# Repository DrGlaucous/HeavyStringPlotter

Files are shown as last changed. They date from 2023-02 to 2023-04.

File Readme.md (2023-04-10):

  

## String Plotter

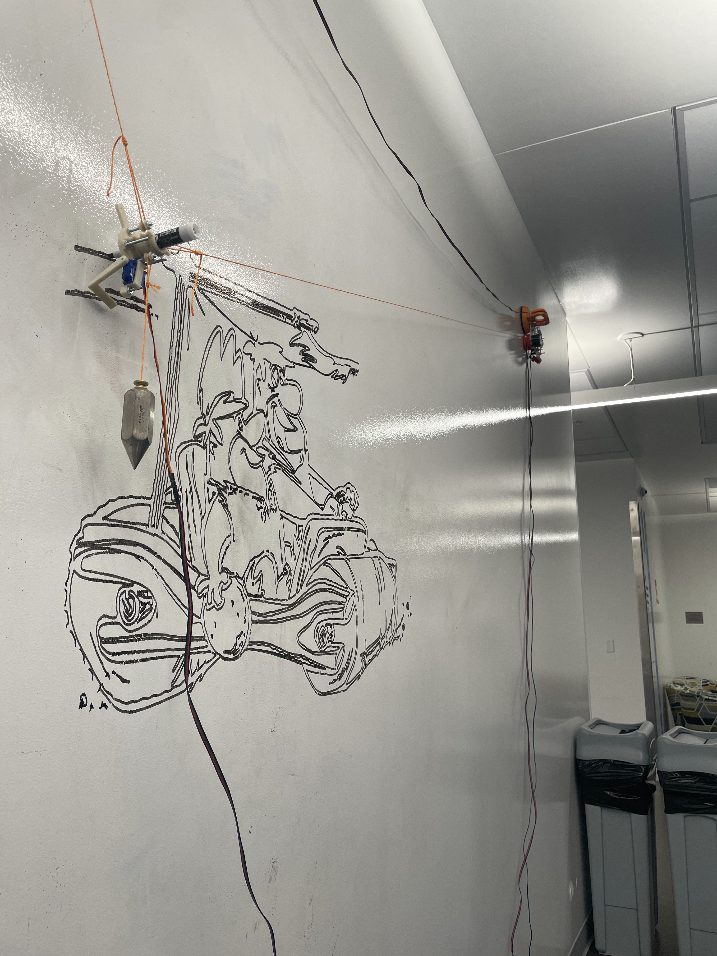
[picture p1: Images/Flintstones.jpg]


---

  This is the repo for a whiteboard mounted string plotter, or *polarograph*.
It is designed to use standard 3D printer hardware and suction cups to mount to virtually any smooth surface or whiteboard. 
When not in use, it compacts nicely into a shoebox for easy transportation.

---
The plotter itself is not particularly fancy or innovative. Better designs probably exist.

What makes this plotter unique is that it makes use of the ESP32 and [FluidNC](https://github.com/bdring/FluidNC) for control. 

This allows versatile control over how the plotter will behave and a whole host of CAM software for generating plots, all wirelessly.

Several modifications have been made to the FluidNC firmware to optimize its use for this application.
New Commands:
* **$SAD = [distance in mm]** *Set Anchor Distance: set the distance between left and right anchor points when the plotter is set up.*
* **$DMC = [1/0]** *Direct Motor Control: Jogging with X and Y will move each motor directly without any kinematic conversion, to be used in conjunction with **\$CGL** *
* **$CGL = [0/1]** *Calibrate Gondola Location: 0 for left, 1 for right. Indented to help the plotter calculate the distance between anchors, but I find that using a tape measure and the **\$SAD** command is quicker and easier.*

The commands assume the plotter's 0,0 is directly below the left anchor. How far down can be set in the config file (the one I used can be found in the firmware folder with the fluidNC build itself).

---
Hardware:

* For the controller, I used a ESP32 Lolin32 Lite board. These can be picked up for extremely cheap online compared to other ESP32 models.
* I used two A4988 stepStick modules to control the steppers, which were just what I had on hand. Any type of motor will work, so long as it has somewhat decent torque and a NEMA17 form factor.
* A cheap 9g servo is used to actuate the marker.
* A buck-boost regulator supplies 3.3 volts to the controller and servo.
* I used a refitted 12V laptop power supply to give the contraption power, but it should be able to work on any voltage within the stepper controller and regulator's range. (higher voltages will mean more holding torque from the motors.)

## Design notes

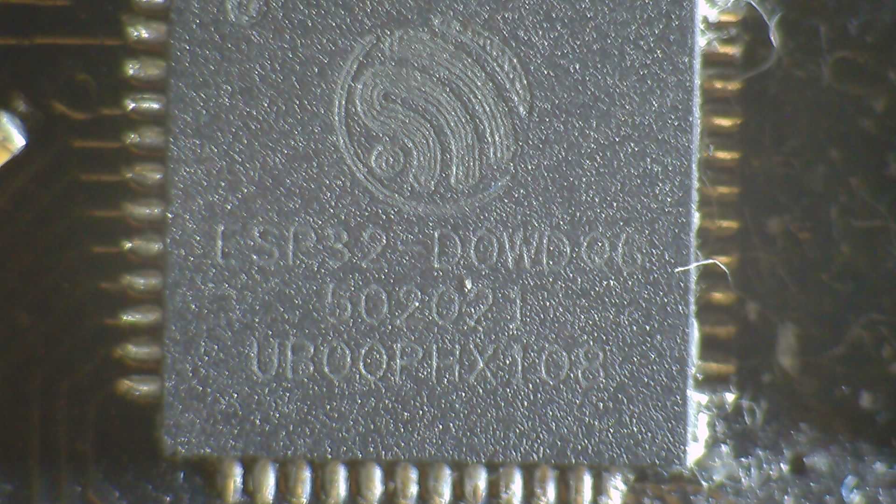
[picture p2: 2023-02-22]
Schematic/ESP32 Plotter/Info/WIN_20230220_11_58_59_Pro.jpg

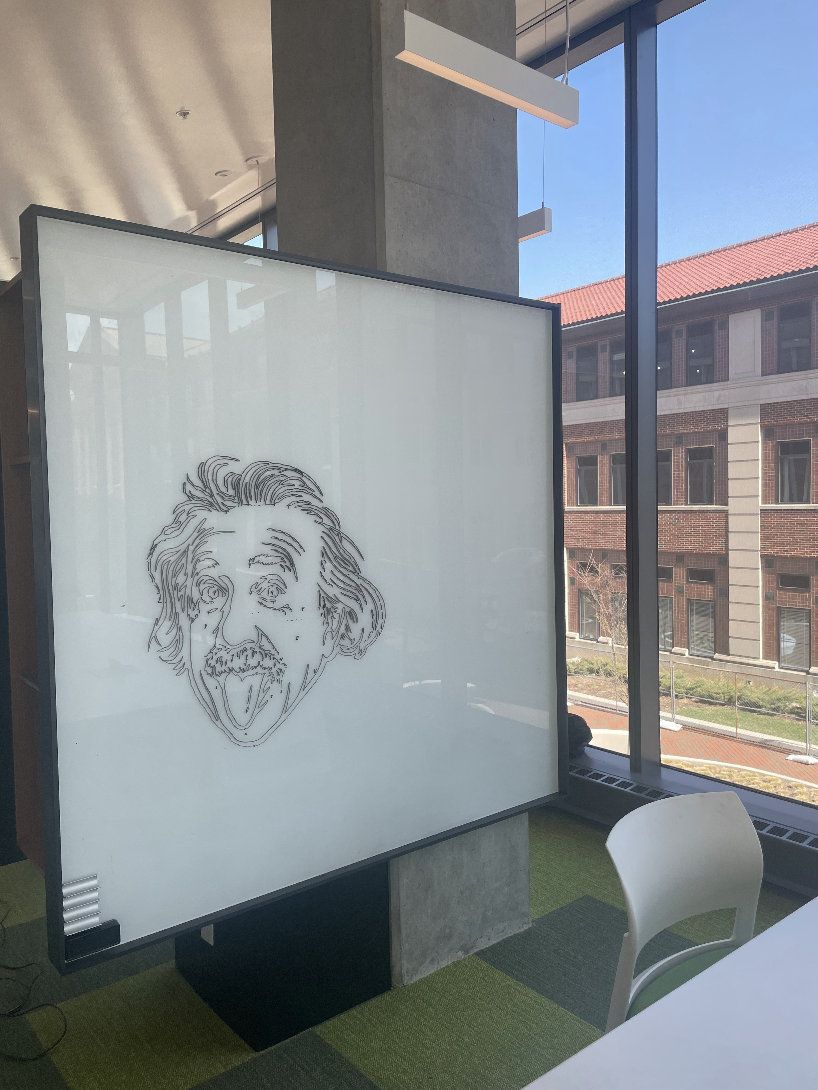
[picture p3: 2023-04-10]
Images/Einstein.jpg

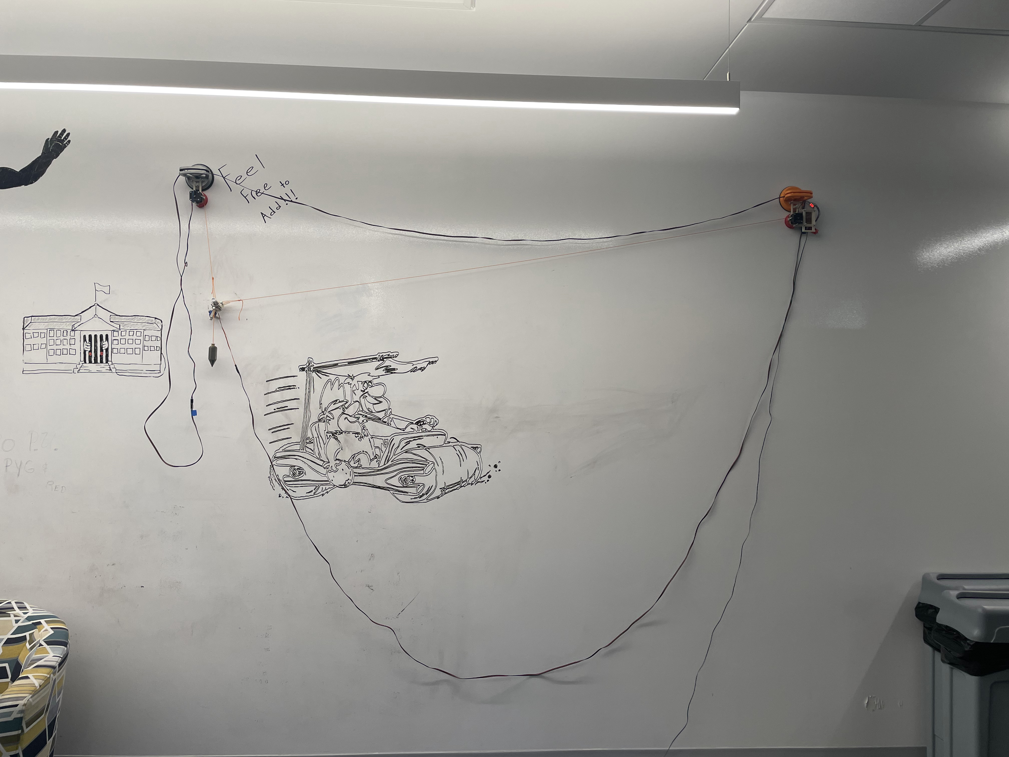
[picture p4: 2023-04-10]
Images/Flintstones2.jpg

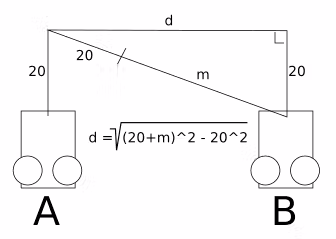
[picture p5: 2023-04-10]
Firmware/Reference/MathImage.png

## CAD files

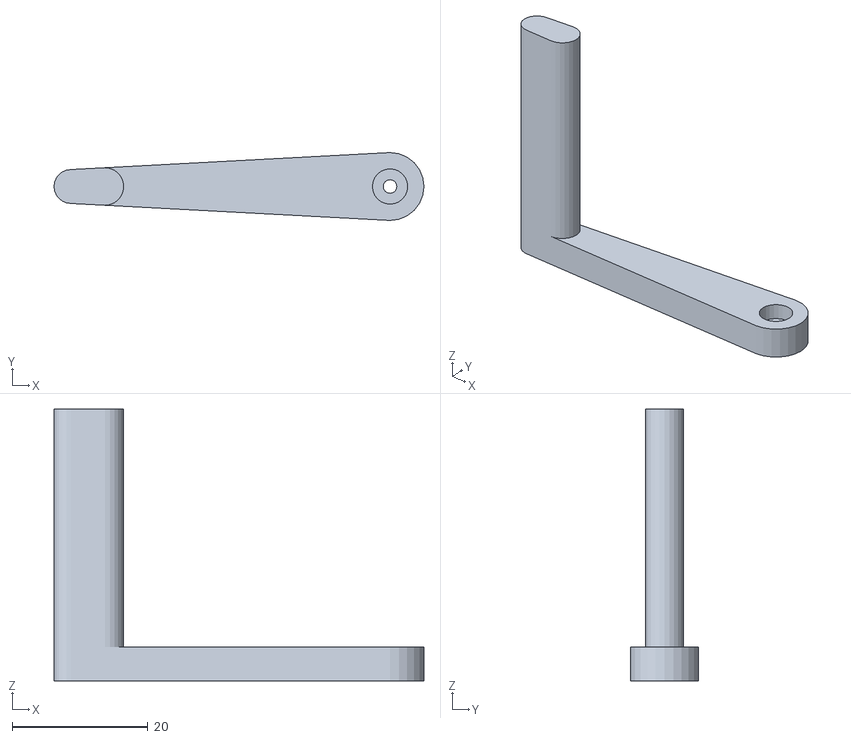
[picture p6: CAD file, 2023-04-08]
CAD/STLs/ImobilePlotter/ServoArmTall.stl
54.5 x 10.0 x 40.0

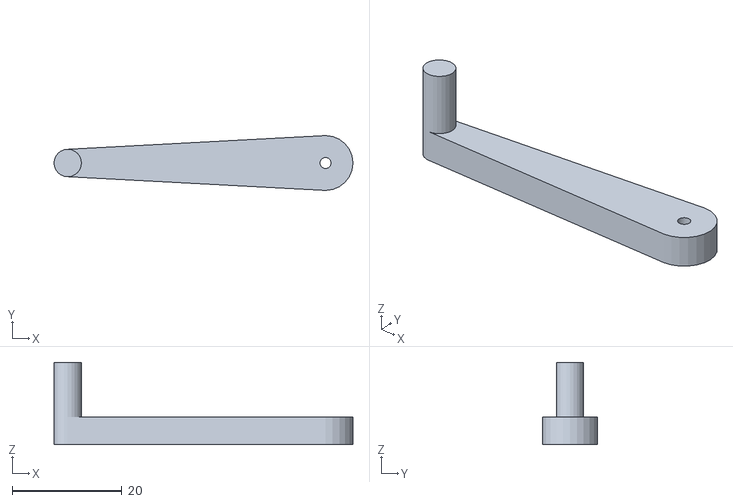
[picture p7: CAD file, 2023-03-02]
CAD/STLs/MobilePlotter/ServoArmL.stl
54.5 x 10.0 x 15.0

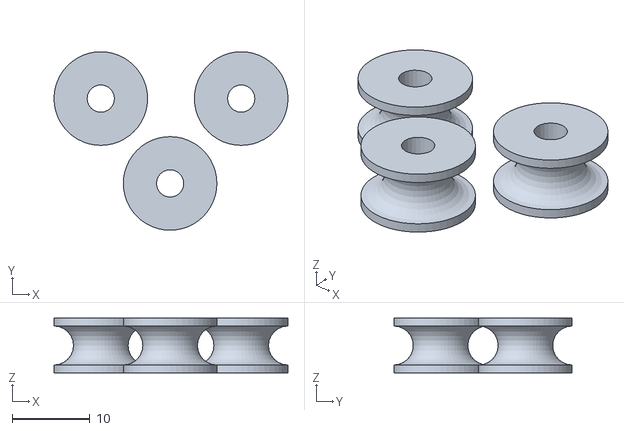
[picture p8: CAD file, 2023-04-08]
CAD/STLs/ImobilePlotter/StringHookX3Kit.stl
30.0 x 22.9 x 7.00

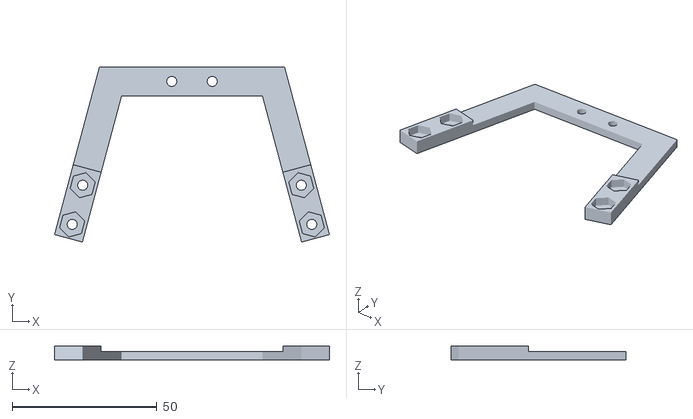
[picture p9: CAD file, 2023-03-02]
CAD/STLs/MobilePlotter/FrontArmBracket.stl
95.1 x 60.5 x 5.00

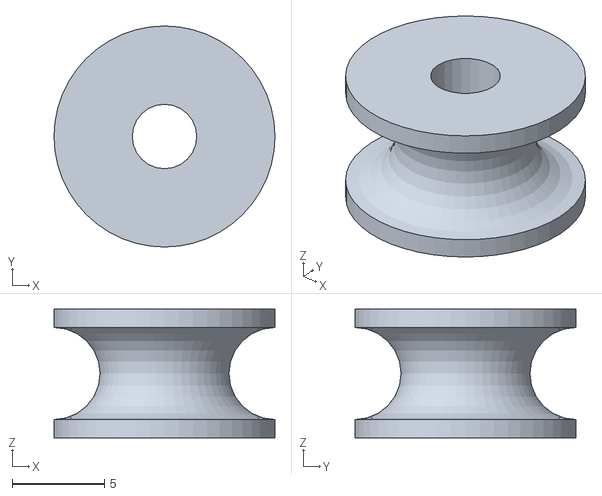
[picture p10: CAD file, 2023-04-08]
CAD/STLs/ImobilePlotter/StringHook.stl
12.0 x 12.0 x 7.00

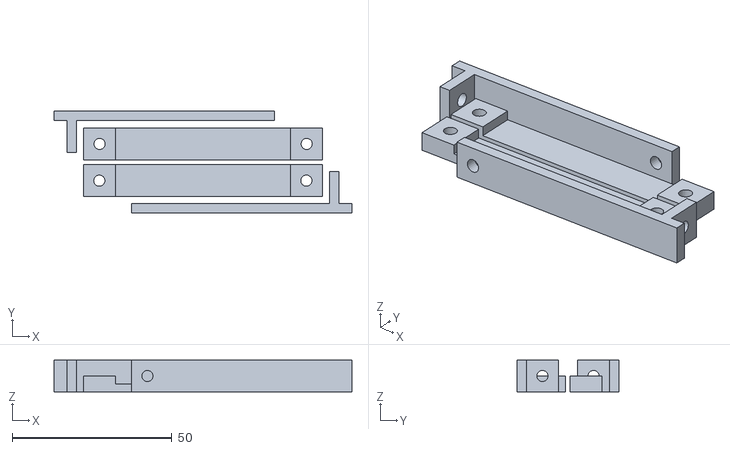
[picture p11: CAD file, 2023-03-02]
CAD/STLs/MobilePlotter/KitStrapLeg.stl
93.2 x 32.0 x 10.0

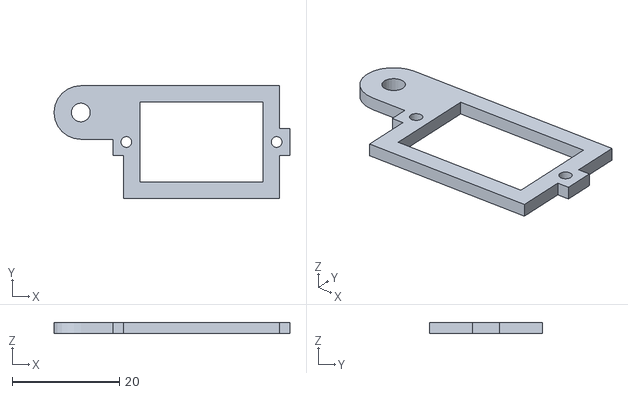
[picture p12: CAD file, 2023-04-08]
CAD/STLs/ImobilePlotter/VoltmeterBracket.stl
44.0 x 21.0 x 2.00

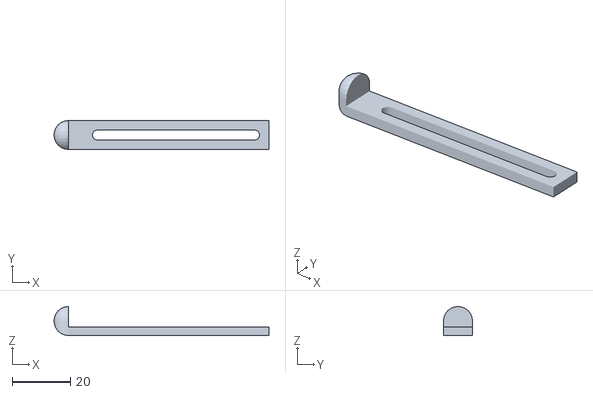
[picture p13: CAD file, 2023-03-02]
CAD/STLs/MobilePlotter/FrontArmExtenderL.stl
74.0 x 10.0 x 10.0

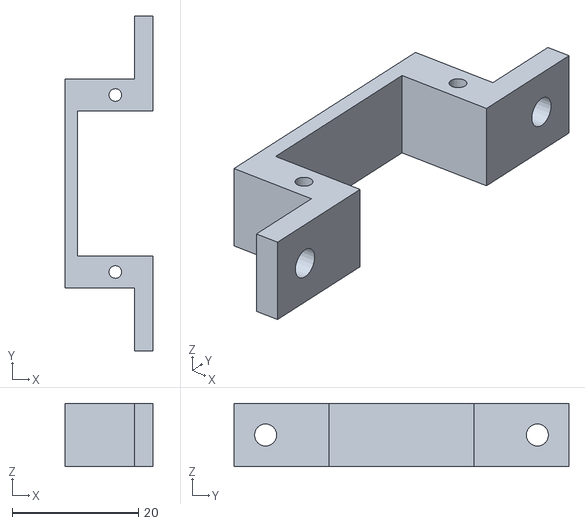
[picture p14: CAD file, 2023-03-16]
CAD/STLs/ImobilePlotter/ServoBracket.stl
14.0 x 53.0 x 10.0

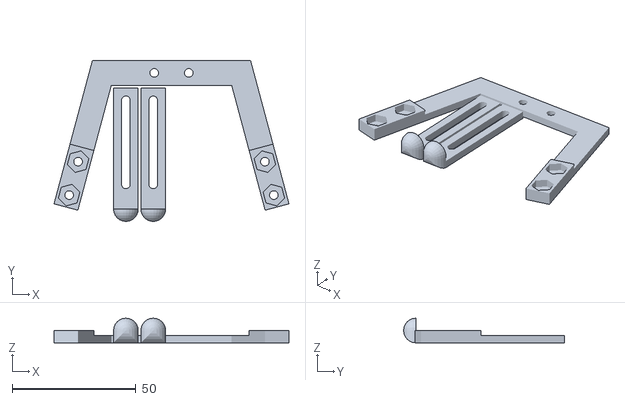
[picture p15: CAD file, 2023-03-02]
CAD/STLs/MobilePlotter/FrontArmKit.stl
95.1 x 65.1 x 10.0

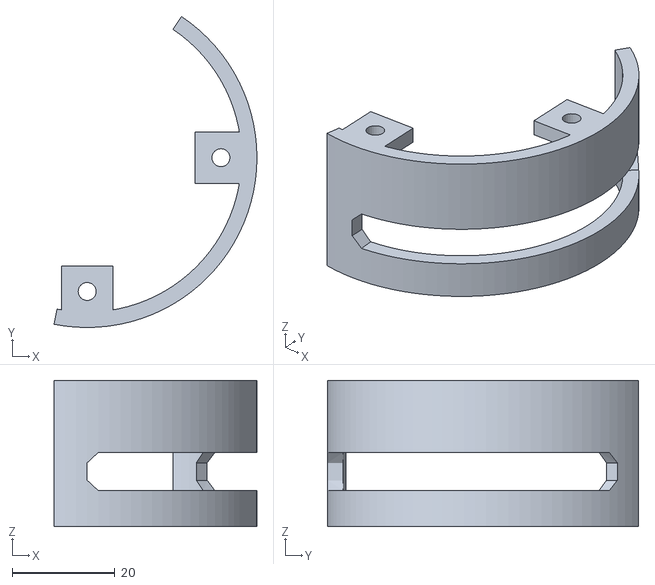
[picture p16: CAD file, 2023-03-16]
CAD/STLs/ImobilePlotter/StringGuideLeft.stl
39.4 x 60.4 x 28.4

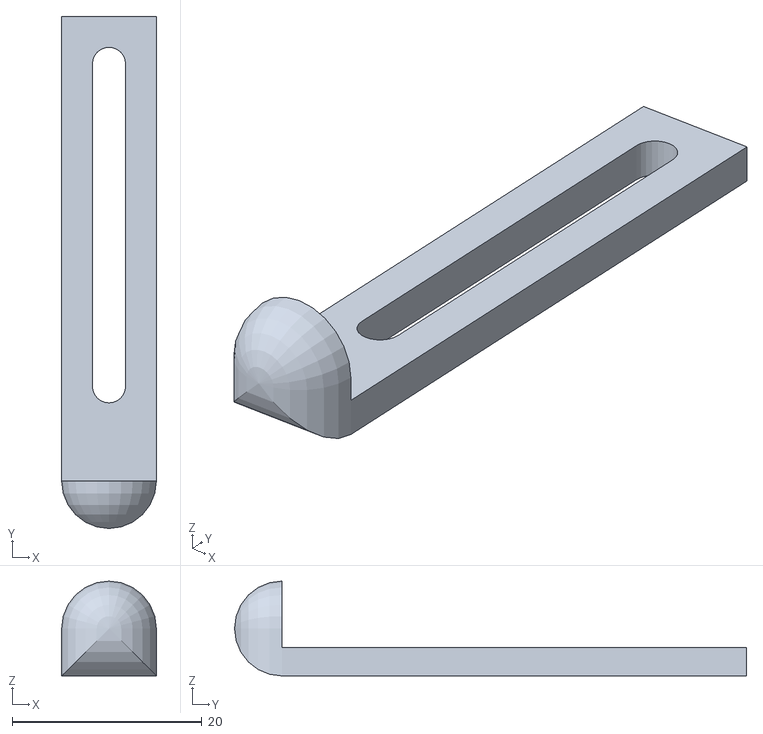
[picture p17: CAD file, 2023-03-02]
CAD/STLs/MobilePlotter/FrontArmExtender.stl
10.0 x 54.0 x 10.0

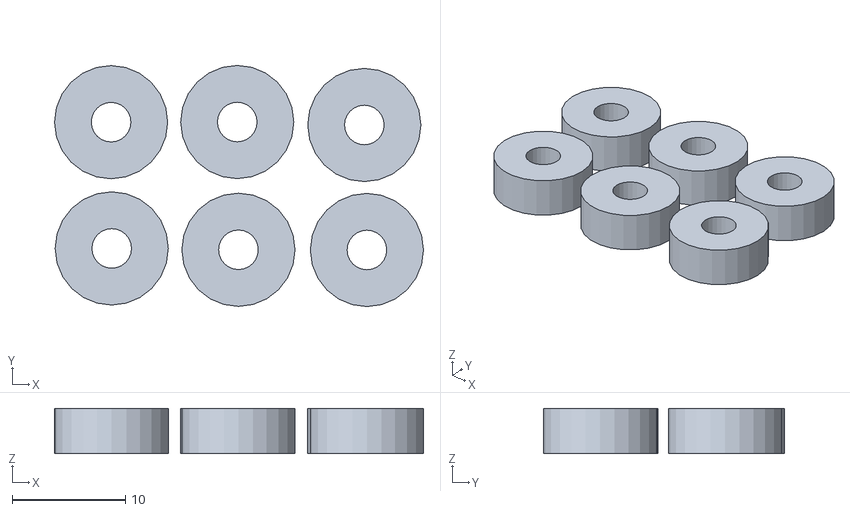
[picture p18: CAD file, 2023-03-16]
CAD/STLs/ImobilePlotter/BracketSpacerKit.stl
32.6 x 21.3 x 4.00

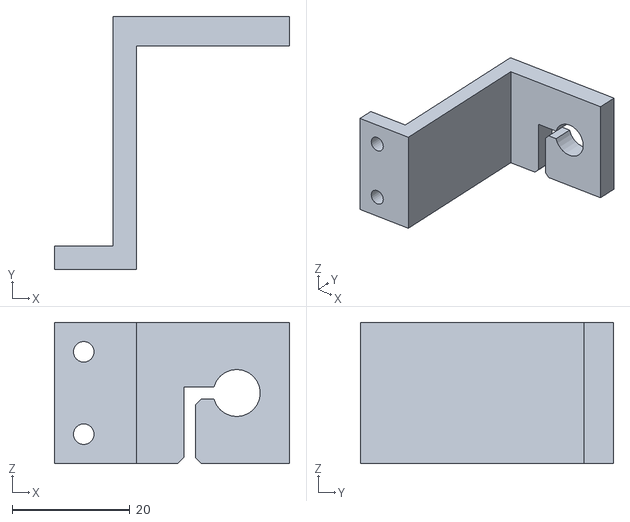
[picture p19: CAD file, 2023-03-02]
CAD/STLs/MobilePlotter/MountStringVer2.stl
40.0 x 43.0 x 24.0

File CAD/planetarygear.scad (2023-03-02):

// Planetary gear bearing (customizable)

// outer diameter of ring
D=50;
// thickness
T=15;
// clearance
tol=0.2;
number_of_planets=5;
number_of_teeth_on_planets=7;
approximate_number_of_teeth_on_sun=9;
// pressure angle
P=30;//[30:60]
// number of teeth to twist across
nTwist=1;
// width of hexagonal hole.  For hex safts.
w=6.7;
// Shaft radius.  For round saft with a flat.
sd=5;
// Shaft thinkness at flat  For round saft with a flat..
st=4.5;
// Shaft type: 0=hex, 1=round w/flat.
stype=1;
// Planet axile diameter.
pad=3.5;

DR=0.5*1;// maximum depth ratio of teeth

m=round(number_of_planets);
np=round(number_of_teeth_on_planets);
ns1=approximate_number_of_teeth_on_sun;
k1=round(2/m*(ns1+np));
k= k1*m%2!=0 ? k1+1 : k1;
ns=k*m/2-np;
echo(ns);
nr=ns+2*np;
pitchD=0.9*D/(1+min(PI/(2*nr*tan(P)),PI*DR/nr));
pitch=pitchD*PI/nr;
echo(pitch);
helix_angle=atan(2*nTwist*pitch/T);
echo(helix_angle);

phi=$t*360/m;

translate([0,0,T/2]){
	difference(){ // This makes the outer ring.
		cylinder(r=D/2,h=T,center=true,$fn=100);
		herringbone(nr,pitch,P,DR,-tol,helix_angle,T+0.2);
		difference(){
			translate([0,-D/2,0])rotate([90,0,0])monogram(h=10);
			cylinder(r=D/2-0.25,h=T+2,center=true,$fn=100);
		}
	}
	rotate([0,0,(np+1)*180/ns+phi*(ns+np)*2/ns])
	difference(){ // This makes the sun.
		mirror([0,1,0])
			herringbone(ns,pitch,P,DR,tol,helix_angle,T);
		if(stype==0)
			cylinder(r=w/sqrt(3),h=T+1,center=true,$fn=6);
		else
			difference(){ // This makes a hole for a flat shaft.
				cylinder(r=sd/2,h=T+1,center=true,$fn=100);
				translate([st-(sd/2),-(sd/2),-(T+1)/2])
					cube([sd, sd, T+1]);	// This is the flat in the shaft hole.
			}
	}
	// Now make the planets.
	for(i=[1:m])
		rotate([0,0,i*360/m+phi])
			translate([pitchD/2*(ns+np)/nr,0,0])
				rotate([0,0,i*ns/m*360/np-phi*(ns+np)/np-phi])
					difference(){ // make an axial hole in each planet.
						herringbone(np,pitch,P,DR,tol,helix_angle,T);
						cylinder(r=pad/2,h=T+1,center=true,$fn=100);	// This is the hole.
					}
}


// Makes the teeth on the inside of the outer ring.
module monogram(h=0)
linear_extrude(height=h,center=true)
translate(-[3,2.5])union(){
	difference(){
		//square([4,5]);
		translate([1,1]);square([0,0]);
	}
	//square([6,1]);
	translate([0,2]);//square([2,1]);
}

module herringbone(
	number_of_teeth=15,
	circular_pitch=10,
	pressure_angle=28,
	depth_ratio=1,
	clearance=0,
	helix_angle=0,
	gear_thickness=5){
union(){
	gear(number_of_teeth,
		circular_pitch,
		pressure_angle,
		depth_ratio,
		clearance,
		helix_angle,
		gear_thickness/2);
	mirror([0,0,1])
		gear(number_of_teeth,
			circular_pitch,
			pressure_angle,
			depth_ratio,
			clearance,
			helix_angle,
			gear_thickness/2);
}}

module gear (
	number_of_teeth=15,
	circular_pitch=10,
	pressure_angle=28,
	depth_ratio=1,
	clearance=0,
	helix_angle=0,
	gear_thickness=5,
	flat=false){
pitch_radius = number_of_teeth*circular_pitch/(2*PI);
twist=tan(helix_angle)*gear_thickness/pitch_radius*180/PI;

flat_extrude(h=gear_thickness,twist=twist,flat=flat)
	gear2D (
		number_of_teeth,
		circular_pitch,
		pressure_angle,
		depth_ratio,
		clearance);
}

module flat_extrude(h,twist,flat){
	if(flat==false)
		linear_extrude(height=h,twist=twist,slices=twist/6)child(0);
	else
		child(0);
}

module gear2D (
	number_of_teeth,
	circular_pitch,
	pressure_angle,
	depth_ratio,
	clearance){
pitch_radius = number_of_teeth*circular_pitch/(2*PI);
base_radius = pitch_radius*cos(pressure_angle);
depth=circular_pitch/(2*tan(pressure_angle));
outer_radius = clearance<0 ? pitch_radius+depth/2-clearance : pitch_radius+depth/2;
root_radius1 = pitch_radius-depth/2-clearance/2;
root_radius = (clearance<0 && root_radius1<base_radius) ? base_radius : root_radius1;
backlash_angle = clearance/(pitch_radius*cos(pressure_angle)) * 180 / PI;
half_thick_angle = 90/number_of_teeth - backlash_angle/2;
pitch_point = involute (base_radius, involute_intersect_angle (base_radius, pitch_radius));
pitch_angle = atan2 (pitch_point[1], pitch_point[0]);
min_radius = max (base_radius,root_radius);

intersection(){
	rotate(90/number_of_teeth)
		circle($fn=number_of_teeth*3,r=pitch_radius+depth_ratio*circular_pitch/2-clearance/2);
	union(){
		rotate(90/number_of_teeth)
			circle($fn=number_of_teeth*2,r=max(root_radius,pitch_radius-depth_ratio*circular_pitch/2-clearance/2));
		for (i = [1:number_of_teeth])rotate(i*360/number_of_teeth){
			halftooth (
				pitch_angle,
				base_radius,
				min_radius,
				outer_radius,
				half_thick_angle);		
			mirror([0,1])halftooth (
				pitch_angle,
				base_radius,
				min_radius,
				outer_radius,
				half_thick_angle);
		}
	}
}}

module halftooth (
	pitch_angle,
	base_radius,
	min_radius,
	outer_radius,
	half_thick_angle){
index=[0,1,2,3,4,5];
start_angle = max(involute_intersect_angle (base_radius, min_radius)-5,0);
stop_angle = involute_intersect_angle (base_radius, outer_radius);
angle=index*(stop_angle-start_angle)/index[len(index)-1];
p=[[0,0], // The more of these the smoother the involute shape of the teeth.
	involute(base_radius,angle[0]+start_angle),
	involute(base_radius,angle[1]+start_angle),
	involute(base_radius,angle[2]+start_angle),
	involute(base_radius,angle[3]+start_angle),
	involute(base_radius,angle[4]+start_angle),
	involute(base_radius,angle[5]+start_angle)];

difference(){
	rotate(-pitch_angle-half_thick_angle)polygon(points=p);
	square(2*outer_radius);
}}

// Mathematical Functions
//===============

// Finds the angle of the involute about the base radius at the given distance (radius) from it's center.
//source: http://www.mathhelpforum.com/math-help/geometry/136011-circle-involute-solving-y-any-given-x.html

function involute_intersect_angle (base_radius, radius) = sqrt (pow (radius/base_radius, 2) - 1) * 180 / PI;

// Calculate the involute position for a given base radius and involute angle.

function involute (base_radius, involute_angle) =
[
	base_radius*(cos (involute_angle) + involute_angle*PI/180*sin (involute_angle)),
	base_radius*(sin (involute_angle) - involute_angle*PI/180*cos (involute_angle))
];

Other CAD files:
CAD/STLs/ImobilePlotter/GondolaBase.stl
CAD/STLs/MobilePlotter/ServoArm.stl
CAD/STLs/ImobilePlotter/MarkerHolder.stl
CAD/STLs/MobilePlotter/MountMarker.stl
CAD/STLs/ImobilePlotter/BatteryRest.stl
CAD/STLs/ImobilePlotter/BracketSpacer.stl
CAD/STLs/ImobilePlotter/CornerMotorBracket.stl
CAD/STLs/ImobilePlotter/ElectronicsBracket.stl
CAD/STLs/ImobilePlotter/GondolaHookLoop.stl
CAD/STLs/ImobilePlotter/GondolaPartsKit.stl
CAD/STLs/ImobilePlotter/StringGuideRight.stl
CAD/STLs/MobilePlotter/BackLeg.stl
CAD/STLs/MobilePlotter/Base.stl
CAD/STLs/MobilePlotter/BatteryStrap.stl
CAD/STLs/MobilePlotter/MountServo.stl
CAD/STLs/MobilePlotter/MountString.stl
CAD/STLs/MobilePlotter/Pulley.stl

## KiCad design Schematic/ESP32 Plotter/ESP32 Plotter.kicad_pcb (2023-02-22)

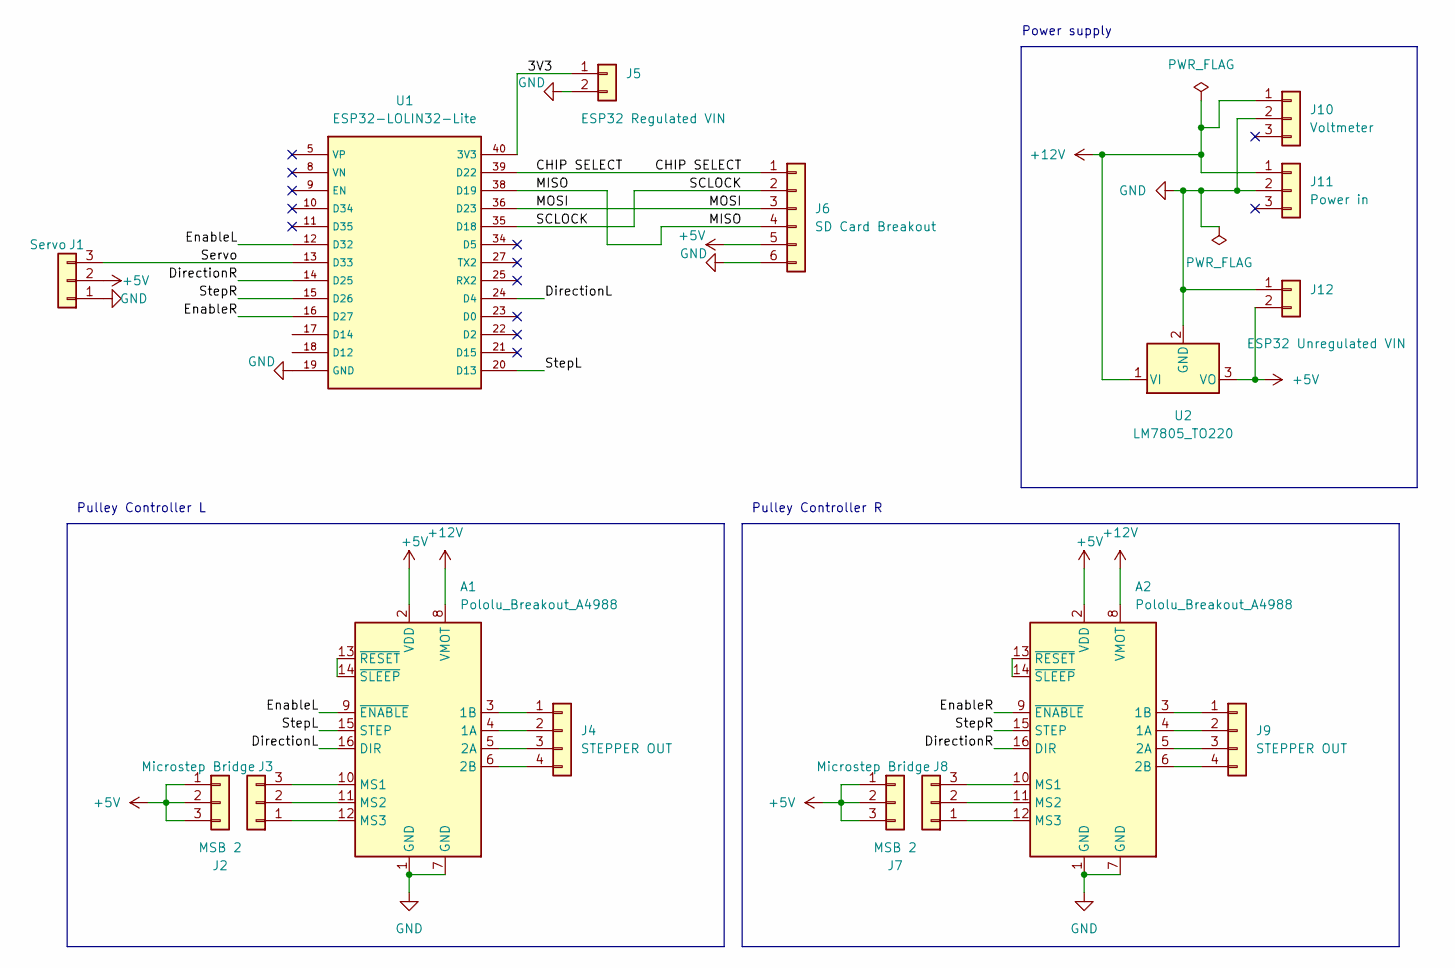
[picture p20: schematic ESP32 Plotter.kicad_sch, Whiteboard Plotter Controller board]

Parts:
A1, A2: Pololu_Breakout_A4988; Pololu_Breakout-16_15.2x20.3mm
J1: Servo; PinHeader_1x03_P2.54mm_Vertical
J2, J7: MSB 2; PinHeader_1x03_P2.54mm_Vertical
J3, J8: Microstep Bridge; PinHeader_1x03_P2.54mm_Vertical
J4, J9: STEPPER OUT; PinHeader_1x04_P2.54mm_Vertical
J5: ESP32 Regulated VIN; PinHeader_1x02_P2.54mm_Vertical
J6: SD Card Breakout; PinHeader_1x06_P2.54mm_Vertical
J10: Voltmeter; PinHeader_1x03_P2.54mm_Vertical
J11: Power in; PinHeader_1x03_P2.54mm_Vertical
J12: ESP32 Unregulated VIN; PinHeader_1x02_P2.54mm_Vertical
U1: ESP32-LOLIN32-Lite
U2: LM7805_TO220; TO-220-3_Vertical

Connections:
+5V: A1.2 (VDD), A2.2 (VDD), J1.2, J2.1, J2.2, J2.3, J6.5, J7.1, J7.2, J7.3, J12.2, U2.3 (VO)
+12V: A1.8 (VMOT), A2.8 (VMOT), J10.1, J11.1, U2.1 (VI)
/3V3: J5.1, U1.40 (3V3)
/CHIP SELECT: J6.1, U1.39 (D22)
/DirectionL: A1.16 (DIR), U1.24 (D4)
/DirectionR: A2.16 (DIR), U1.14 (D25)
/EnableL: A1.9 (~ENABLE), U1.12 (D32)
/EnableR: A2.9 (~ENABLE), U1.16 (D27)
/MISO: J6.4, U1.38 (D19)
/MOSI: J6.3, U1.36 (D23)
/SCLOCK: J6.2, U1.35 (D18)
/Servo: J1.3, U1.13 (D33)
/StepL: A1.15 (STEP), U1.20 (D13)
/StepR: A2.15 (STEP), U1.15 (D26)
GND: A1.1 (GND), A1.7 (GND), A2.1 (GND), A2.7 (GND), J1.1, J5.2, J6.6, J10.2, J11.2, J12.1, U1.19 (GND), U2.2 (GND)
unnamed: A1.3 (1B), J4.1
unnamed: A1.4 (1A), J4.2
unnamed: A1.5 (2A), J4.3
unnamed: A1.6 (2B), J4.4
unnamed: A1.10 (MS1), J3.3
unnamed: A1.11 (MS2), J3.2
unnamed: A1.12 (MS3), J3.1
unnamed: A1.13 (~RESET), A1.14 (~SLEEP)
unnamed: A2.3 (1B), J9.1
unnamed: A2.4 (1A), J9.2
unnamed: A2.5 (2A), J9.3
unnamed: A2.6 (2B), J9.4
unnamed: A2.10 (MS1), J8.3
unnamed: A2.11 (MS2), J8.2
unnamed: A2.12 (MS3), J8.1
unnamed: A2.13 (~RESET), A2.14 (~SLEEP)

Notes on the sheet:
Power supply
Pulley Controller R
Pulley Controller L

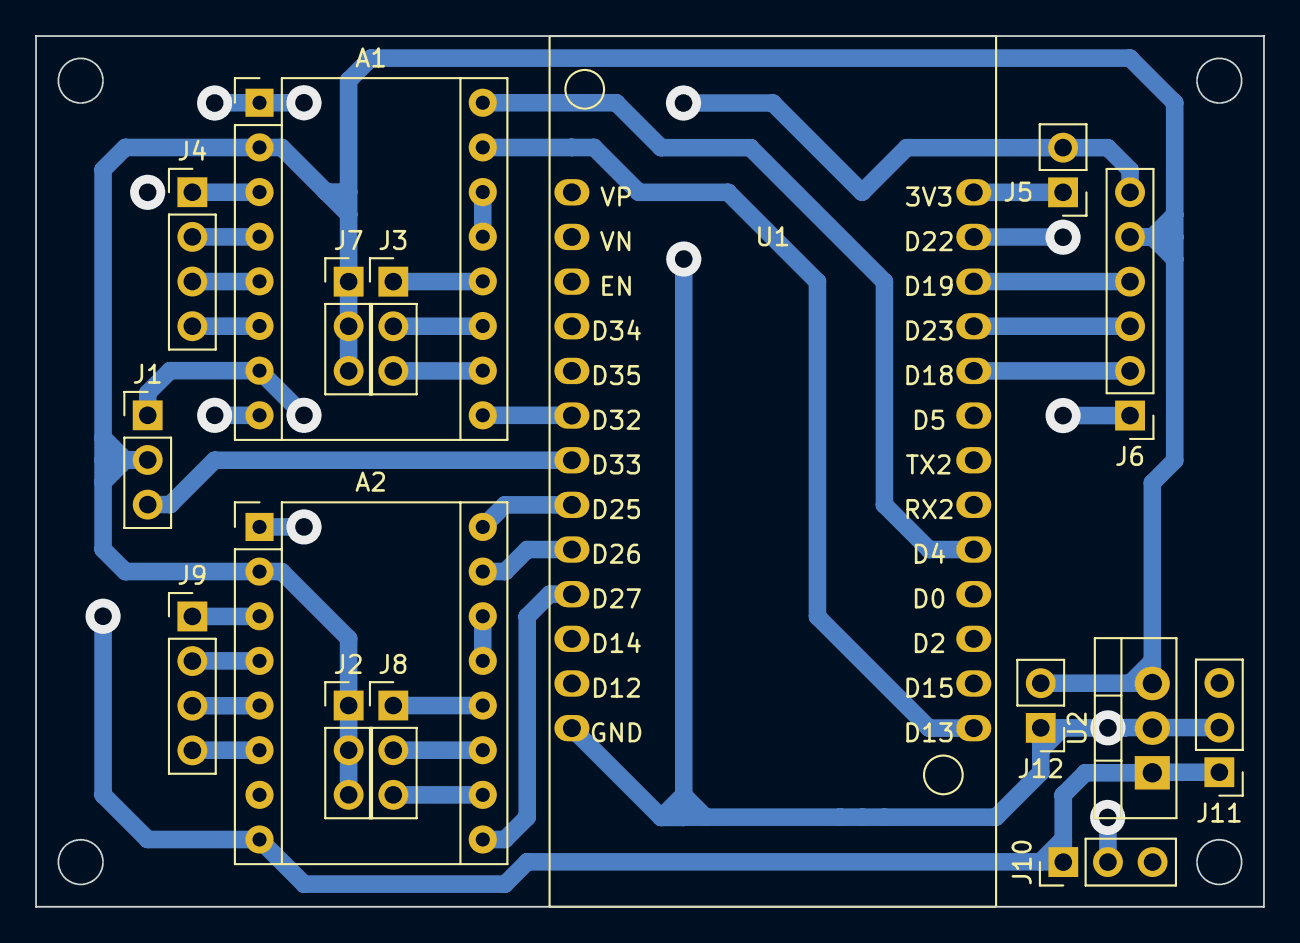
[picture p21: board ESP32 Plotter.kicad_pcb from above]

Board: 2 copper layers, 69.8 x 49.5 mm, 16 parts (0 on the bottom side), 31 nets.

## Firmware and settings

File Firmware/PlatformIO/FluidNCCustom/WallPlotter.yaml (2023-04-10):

name: "ESP32 Dev Controller V4"
board: "WallPlotter ArduinoCNC Shield"



#about wallPlotter:
#left_axis: motor ID (convert from X, Y, Z, to 1, 2, 3, etc)
#left_anchor_x: -428.000 #location of motor from 0,0
#segment_length: 2.0 #Fine-ness of breaking curves into linear movement
#
#this is used if the plotter motors spool up the string instead of pulling it by, overrides steps/mm
#uses_spools: false
#left_axis_steps_per_rotation: 200 #steps per 1 rotation of the spool
#left_axis_diameter_mm_min: 30 #diameter when the spool is empty
#left_axis_diameter_mm_max: 40 #diameter when the spool is completely wound
#left_axis_string_length: 4572 #how long the string is when the spool is completely undone
#
#This stuff is for the new wallPlotter config, for dynamic anchors
#uses_dynamic_anchors: false #anchors will change position each time the plotter is set up
#anchor_config_distance: 500 #distance below each anchor for homing sequence

#may use this, may not...
#    use_alt_step_calculations: false
#    left_axis_steps_per_rotation: 3200.00
#    left_axis_diameter_mm: 30.00
#    right_axis_steps_per_rotation: 3200.00
#    right_axis_diameter_mm: 30.00

#old stepspermm 50.92958

kinematics:
  WallPlotter:
    left_axis: 0
    left_anchor_x: 0.000
    left_anchor_y: 400.00
    right_axis: 1
    right_anchor_x: 600.000
    right_anchor_y: 400.00
    segment_length: 1.0

    uses_dynamic_anchors: true
    anchor_config_distance: 400

    

stepping:
  engine: RMT
  idle_ms: 255
  dir_delay_us: 1
  pulse_us: 1
  disable_delay_us: 0

axes:
  
  x:
    steps_per_mm: 32.45
    max_rate_mm_per_min: 4000
    acceleration_mm_per_sec2: 400
    max_travel_mm: 4000
    homing:
      cycle: 0
      mpos_mm: 0
      positive_direction: false
    
    motor0:
      stepstick:
        direction_pin: gpio.4
        step_pin: gpio.13
        disable_pin: gpio.32

  y:
    steps_per_mm: 32.45
    max_rate_mm_per_min: 4000
    acceleration_mm_per_sec2: 400
    max_travel_mm: 4000
    homing:
      cycle: 0
      mpos_mm: 0
      positive_direction: false

    motor0:
      limit_all_pin: NO_PIN
      stepstick:
        direction_pin: gpio.25
        step_pin: gpio.26
        disable_pin: gpio.27

  # z:
  #   steps_per_mm: 2000
  #   max_rate_mm_per_min: 500
  #   acceleration_mm_per_sec2: 100
  #   max_travel_mm: 5
  #   homing:
  #     cycle: 0
  #     mpos_mm: 0
  #     positive_direction: false

  #   motor0:
  #     rc_servo:
  #       pwm_hz: 50
  #       output_pin: gpio.33
  #       min_pulse_us: 700
  #       max_pulse_us: 2200

spi:
  miso_pin: gpio.19
  mosi_pin: gpio.23
  sck_pin: gpio.18

sdcard:
  cs_pin: gpio.22
  card_detect_pin: NO_PIN

coolant:
  flood_pin: NO_PIN
  mist_pin:  NO_PIN
        
probe:
  pin: gpio.16:low:pu

# Control pen up/down using a servo that is configured to look like a spindle 
# A cheap blue 9g chinese servo was used. 
# Different min_pulse_us and max_pulse_us may need to be used for other brands...
# 
# As configured the servo will then respond as follows
# M3 S0  is pen up from paper
# M3 S255 is pen down on paper
# If you need to invert motion of servo, invert the values for min_pulse_us and max_pulse_us
besc:
  pwm_hz: 50
  output_pin: gpio.33
  enable_pin: NO_PIN
  direction_pin: NO_PIN
  disable_with_s0: false
  s0_with_disable: true
  spinup_ms: 2000
  spindown_ms: 2000
  tool_num: 100
  speed_map: 0=0.000% 255=100.000%
  min_pulse_us: 700
  max_pulse_us: 2200

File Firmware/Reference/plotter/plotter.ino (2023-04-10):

#include "MachineDefs.h"
 
//circumference of spool
#define spoolCirc 94.2 

//steps per full rotation (number from https://github.com/robjampar/Stepper , never bothered to calculate it propery myself)
#define stepsPerRotation 4075.7728395

//number of steps for each full rotation
#define stepsPerMM (stepsPerRotation/spoolCirc)

//longest allowed line segment before splitting
#define maxSegmentLength 10 

#define EEPROM_LEFT_ADDR 0
#define EEPROM_RIGHT_ADDR 4
#define EEPROM_DISPARITY_ADDR 8
#define EEPROM_STOPPED_AT_ADDR 12
#define EEPROM_CURRENT_PLOT_ADDR 16
#define EEPROM_PRINT_SIZE_ADDR 20
#define EEPROM_CENTER_X_ADDR 24
#define EEPROM_CENTER_Y_ADDR 28

long state=0;
long stoppedAt=0; //save of where we stopped, to allow resuming
int currentPlot = 0;
bool resumePlot = false;

//these numbers are left from early versions where setup was done by having exactly 1m of string reeled out on both left and right and a fix disparity of 1m between anchors. This is now set up by user instead.
long disparity = 1000;  //distance between anchor points 
long currentLeftSteps  = 1000*stepsPerMM; 
long currentRightSteps = 1000*stepsPerMM;
float centerX = 500; //starting x pos
float centerY = 866; //starting x pos

bool stopPressed = false;

int program = 0; //0 is start program, responding to IR 

//manual control
int manualLeft = 0, manualRight = 0;
float printSize = 1.0;
bool continousManualDrive = true;

//bookkeeping for sub segmenting lines
static float prevX = 0;
static float prevY = 0;
static int currentSubSegment = 0;

void storePositionInEEPROM();

void setup()
{  
#ifdef USE_DATA_FROM_DISK
  //store constant values into mock eeprom, wait 1sec first to allow storage
  delayMicroseconds(1000000);  
  storePositionInEEPROM();
  printf("[disparity, currentLeftSteps, currentRightSteps, centerX, centerY]\n");
  printf("%ld, %ld, %ld, %f, %f\n", disparity, currentLeftSteps, currentRightSteps, centerX, centerY);  
#endif
  
#ifdef SERIAL_DEBUG
  //Initialize serial and wait for port to open:
    Serial.begin(9600); 
    SER_PRINTLN("Setup");
#endif
  
  //initialize IR  
  setupIR();

  //initialize steppers
  setupStep();

  //initialize servo
  setupServo();
  
  //initialize SD card
  setupData();
  
  //read stored position from EEPROM
  currentLeftSteps = eepromReadLong(EEPROM_LEFT_ADDR);  
  currentRightSteps = eepromReadLong(EEPROM_RIGHT_ADDR);  
  disparity = eepromReadLong(EEPROM_DISPARITY_ADDR);  
  stoppedAt = eepromReadLong(EEPROM_STOPPED_AT_ADDR);  
  currentPlot = eepromReadLong(EEPROM_CURRENT_PLOT_ADDR);    
  if(stoppedAt > 0) {
    //preserve chosen size iff we stopped in the middle of a plot
    printSize = eepromReadFloat(EEPROM_PRINT_SIZE_ADDR);        
  }
  centerX = eepromReadFloat(EEPROM_CENTER_X_ADDR);    
  centerY = eepromReadFloat(EEPROM_CENTER_Y_ADDR);    
  
#ifdef SERIAL_DEBUG
  Serial.print("Disparity=");
  Serial.println(disparity);
#endif

#ifdef NO_REMOTE
   //fake start a print since we dont have IR control
   printSize = 1;
   program = 1; //start print
   currentPlot = 4; 
#endif  
}

unsigned long lastEEPromStore = 0;

void storePositionInEEPROM() {
  unsigned long now = micros();
  //dissallow storing to eeprom more than once a second (avoid repeated ir keystrokes)
  if((lastEEPromStore+1000000) <= now) {

    SER_PRINTLN("EEPROM: Store");

    lastEEPromStore = now;
    eepromWriteLong(EEPROM_LEFT_ADDR, currentLeftSteps);  
    eepromWriteLong(EEPROM_RIGHT_ADDR, currentRightSteps);  
    eepromWriteLong(EEPROM_DISPARITY_ADDR, disparity);  
    eepromWriteLong(EEPROM_STOPPED_AT_ADDR, stoppedAt);  
    eepromWriteLong(EEPROM_CURRENT_PLOT_ADDR, currentPlot);  
    eepromWriteFloat(EEPROM_PRINT_SIZE_ADDR, printSize);  
    eepromWriteFloat(EEPROM_CENTER_X_ADDR, centerX);  
    eepromWriteFloat(EEPROM_CENTER_Y_ADDR, centerY);  
  }
}

//coordinate stuff, converts from 2 string lengths to cartesian
//currentLeftSteps is the steps it took to make the current string length
void setOrigo() {
  //convert back from steps to length
    float currentLeft  = currentLeftSteps / stepsPerMM;
    float currentRight = currentRightSteps / stepsPerMM;

    float tmp1 = (currentRight*currentRight-disparity*disparity-currentLeft*currentLeft);//calculate distnace between anchors (a^2-b^2-c^2) (rigth,anchDist,left)
    float tmp2 = (-2*currentLeft*disparity); //get hypotinuse from left string length
    float a = acos(tmp1/tmp2);  //get angle from adj/hyp  
    centerX = currentLeft*cos(a);
    centerY = currentLeft*sin(a);
}

static int prevPen=0;

extern unsigned long lastBatteryLog;

void loop()
{        
    float tmpX, tmpY;
    int tmpPen;

#ifdef HAS_BATTERY_MEASUREMENT    
    unsigned long now = micros();
    if((lastBatteryLog+1000000) <= now) {
      lastBatteryLog = now;
      logBattery(now/1000000);
    }
#endif    
    readIR(); 

    if(program == 0) {
      float left = (manualLeft/spoolCirc) * 360.0;    
      float right = (manualRight/spoolCirc) * 360.0;    
      
      if(manualLeft != 0 || manualRight != 0) {
        currentLeftSteps += manualLeft*stepsPerMM;
        currentRightSteps += manualRight*stepsPerMM;
             
        step(manualLeft*stepsPerMM,manualRight*stepsPerMM,false);
        setOrigo();             
      }

      if(stopPressed || (!continousManualDrive)) {             
        manualLeft = manualRight = 0;
        stopPressed = false;
      }      
    }
    else { 
      if(!getData(currentPlot, state, &tmpX, &tmpY, &tmpPen) || stopPressed) {

        stoppedAt = stopPressed ? state : 0;
                
        //reached the end, go back to manual mode
        state = 0;
        program = 0;
        resumePlot = false; //make sure to not end up in loop if plot cannot be resumed due to missing file or corrupt data        

        //stop with pen up        
        movePen(false, false);
    
        step(0, 0, false); //flush out last line segment

        SER_PRINTLN("Plot done");
        
        //store current position in eeprom 
        storePositionInEEPROM();
      }
      else {
         if(resumePlot && stoppedAt > state) {
           //just skip points until we are at the point where we stopped
             state++;
             prevX = tmpX*printSize;
             prevY = tmpY*printSize;
         }
         else {        
          resumePlot = false;      
          float nextX = tmpX*printSize;
          float nextY = tmpY*printSize;
          boolean nextPen = tmpPen > 0;
          boolean advancePoint = true;
  
          if(state > 0) { //don't try to split first          
            float dx = nextX-prevX;
            float dy = nextY-prevY;
            float len = sqrt(dx*dx+dy*dy);
  
            if(len > maxSegmentLength) {
                //split segment
                int subSegments = 1 + (int)(len/maxSegmentLength);
                if(currentSubSegment == subSegments) {
                    //last segment
                    currentSubSegment = 0; //reset                                                                        
                }
                else {
                    advancePoint = false; //stay on same point        
                    currentSubSegment++;                  
                    
                    nextX = prevX + dx*currentSubSegment/subSegments;
                    nextY = prevY + dy*currentSubSegment/subSegments;
                }
            }
          }
  
          if(advancePoint) {
            state = state+1; //next point
            prevX = nextX;
            prevY = nextY;                   
          }
                  
          float xL = nextX+centerX;
          float xR = nextX+centerX-disparity;
          float y = nextY+centerY;
  
          long newLeft  = sqrt(xL*xL + y*y)*stepsPerMM;
          long newRight = sqrt(xR*xR + y*y)*stepsPerMM;
          
          long dLeft  = (newLeft  - currentLeftSteps);            
          long dRight = (newRight - currentRightSteps);
                  
          currentLeftSteps = newLeft;
          currentRightSteps = newRight;
    
          if(((dLeft == 0) && (dRight == 0))) {
            //no move, ignore
          }
          else {
            movePen(prevPen, false); //adjust pen as necessary  
            step(dLeft, dRight, prevPen != nextPen); //move steppers
            prevPen=nextPen;
          }
      }
    }      
  } 

  //check and disable steppers if idle
  checkDisableSteppers();
}

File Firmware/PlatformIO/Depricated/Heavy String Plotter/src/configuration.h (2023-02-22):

#pragma once

//config stuff goes here

#define TRUE true
#define FALSE false


//when the onboard led is lit
#define LED_ON_STATE false

//network credentials
#define NET_SSID "ESPPlotter"
#define NET_PASSWORD "PassPhrase22"

//stepper configuration pins
#define DIRECTION_L 4
#define ENABLE_L 32
#define STEP_L 13

#define DIRECTION_R 25
#define ENABLE_R 27
#define STEP_R 26

//multiply by microstep value
#define STEPS_PER_MM 16


//servo pin
#define SERVO_PIN 33

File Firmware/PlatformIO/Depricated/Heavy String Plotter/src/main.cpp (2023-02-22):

/*
 Author:	Dr. G
*/

//#include <MIDI.h>
#include <Arduino.h>
#include <HardwareSerial.h>
#include "main.h"
#include "configuration.h"
#include "network.h"


unsigned long MillisecondTicks{};
unsigned long MicrosecondTicks{};
unsigned long LastMillisecondTicks{};//previous values
unsigned long LastMicrosecondTicks{};

//System clock
void GetTicks(void)
{
	LastMillisecondTicks = MillisecondTicks;
	LastMicrosecondTicks = MicrosecondTicks;

	MillisecondTicks = millis();
	MicrosecondTicks = micros();
}

//LED debugging
void BlinkLED(unsigned short time)
{
    //how much time until we turn the LED off
    static unsigned short timeout = 0;

    if(time != 0)
    {
        timeout = time;
    }
    else
        if(LastMillisecondTicks != MillisecondTicks &&
            timeout > 0)
            --timeout;


    if(timeout)
            digitalWrite(LED_BUILTIN, LED_ON_STATE);
        else
            digitalWrite(LED_BUILTIN, !LED_ON_STATE);


}



void setup() {
  
  initNetwork();
  pinMode(22, OUTPUT);

}

void loop() {
  
  GetTicks();
  handleNetwork();

  //BlinkLED(0);//process the blinking of the LED

  //if(MillisecondTicks % 1000 == 0 && LastMillisecondTicks != MillisecondTicks)
  //  BlinkLED(30);

  digitalWrite(22, getSwitchState());

}

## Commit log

2023-02-20 Setup PCB and CNC milling paths
    [ESP32 Plotter.kicad_pcb, ESP32 Plotter.kicad_sch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]
2023-02-22 Added programming references
    It's firmware time
    [ESP32 Plotter.kicad_pcb]
2023-02-22 Switching to FluidNC
    has more and better CNC infrastructure, I just need to update a kinematics file (let's see if I can...)
    [3axis_v4.yaml, 6P_extn_XYZ_HBridge.yaml, 6_Pack_2130_XYZABC.yaml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]
2023-03-02 CAD trial and error
    I think I'm going to switch from a completely mobile unit to a stationary design (motors will be part of the anchor point rather than part of the gondola) because motors lack torque to lift the machine directly (without reduction gears, which are too complicated and require too much hardware)
    [3axis_v4.yaml, FrontArmBracket.stl, FrontArmExtender.stl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]
2023-03-16 STLs, Gcode, and many enhancements
    [BackLeg.stl, Base.stl, BatteryRest.stl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]
2023-04-08 STLs and gcodes
    gcodes should probably be removed
    [ServoArmTall.stl, StringHook.stl, StringHookX3Kit.stl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]
2023-04-10 updates to fluidNC
    added $SAD and several other commands specific to kinematic settings, as well as removed a bug from the wallPlotter kinematics that caused undefined behavior.
    [3axis_v4.yaml, WallPlotter.yaml]
2023-04-10 fixed bugs, added readme and images
    [configuration.h]
